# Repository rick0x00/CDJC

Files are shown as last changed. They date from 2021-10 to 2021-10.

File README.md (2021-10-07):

# Cascading 4017 Decada/Johnson Counter

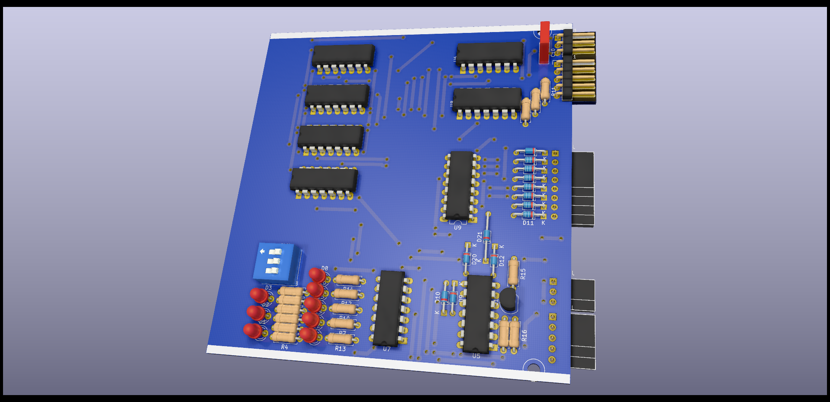
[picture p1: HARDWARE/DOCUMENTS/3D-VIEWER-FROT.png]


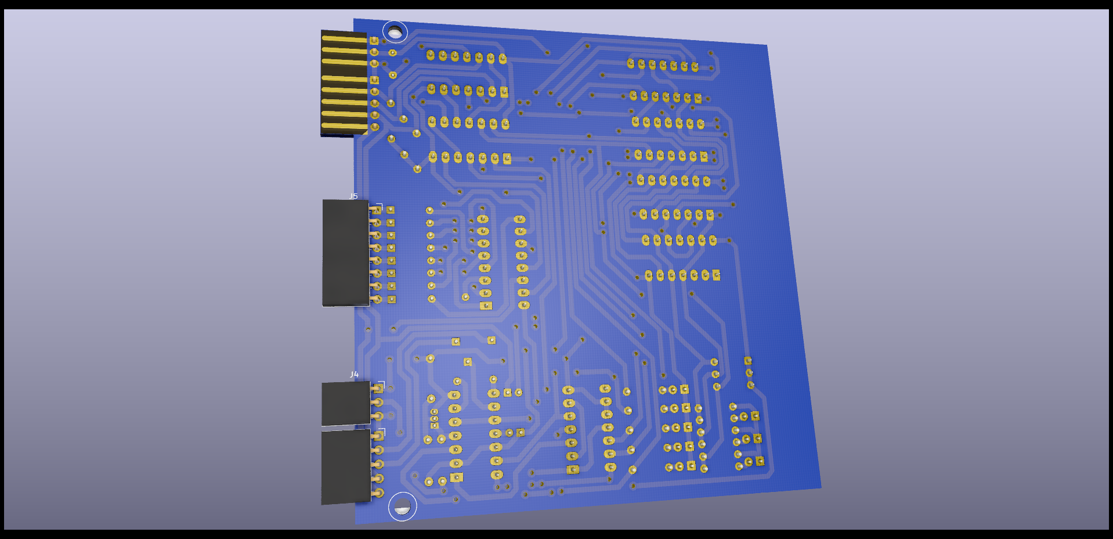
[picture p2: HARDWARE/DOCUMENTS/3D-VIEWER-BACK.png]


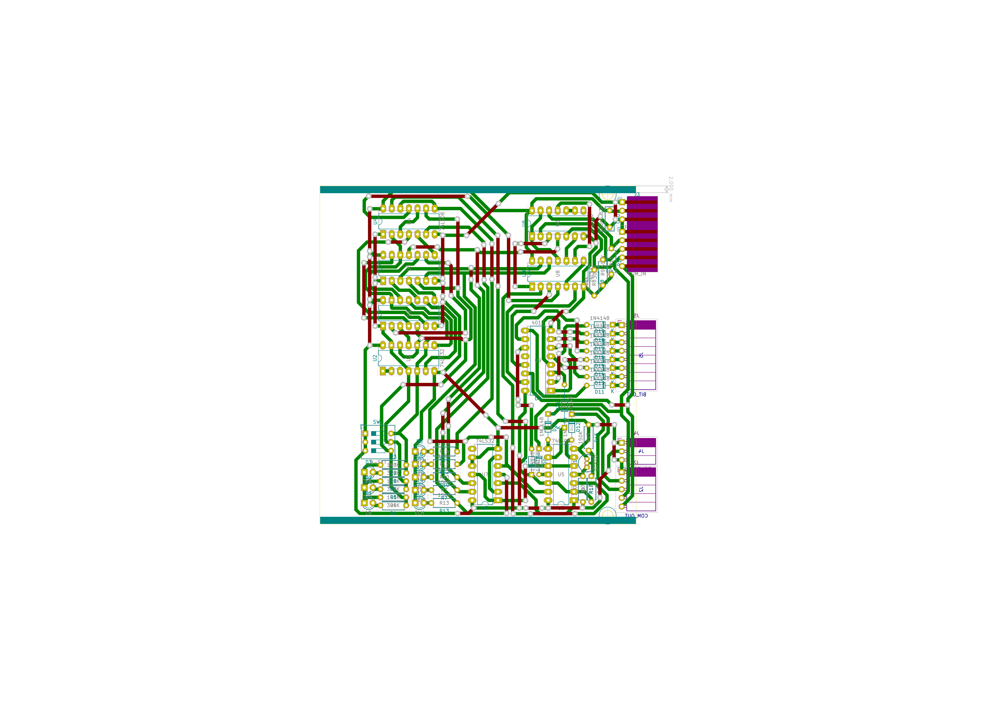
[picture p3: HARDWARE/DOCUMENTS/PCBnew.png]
PCB


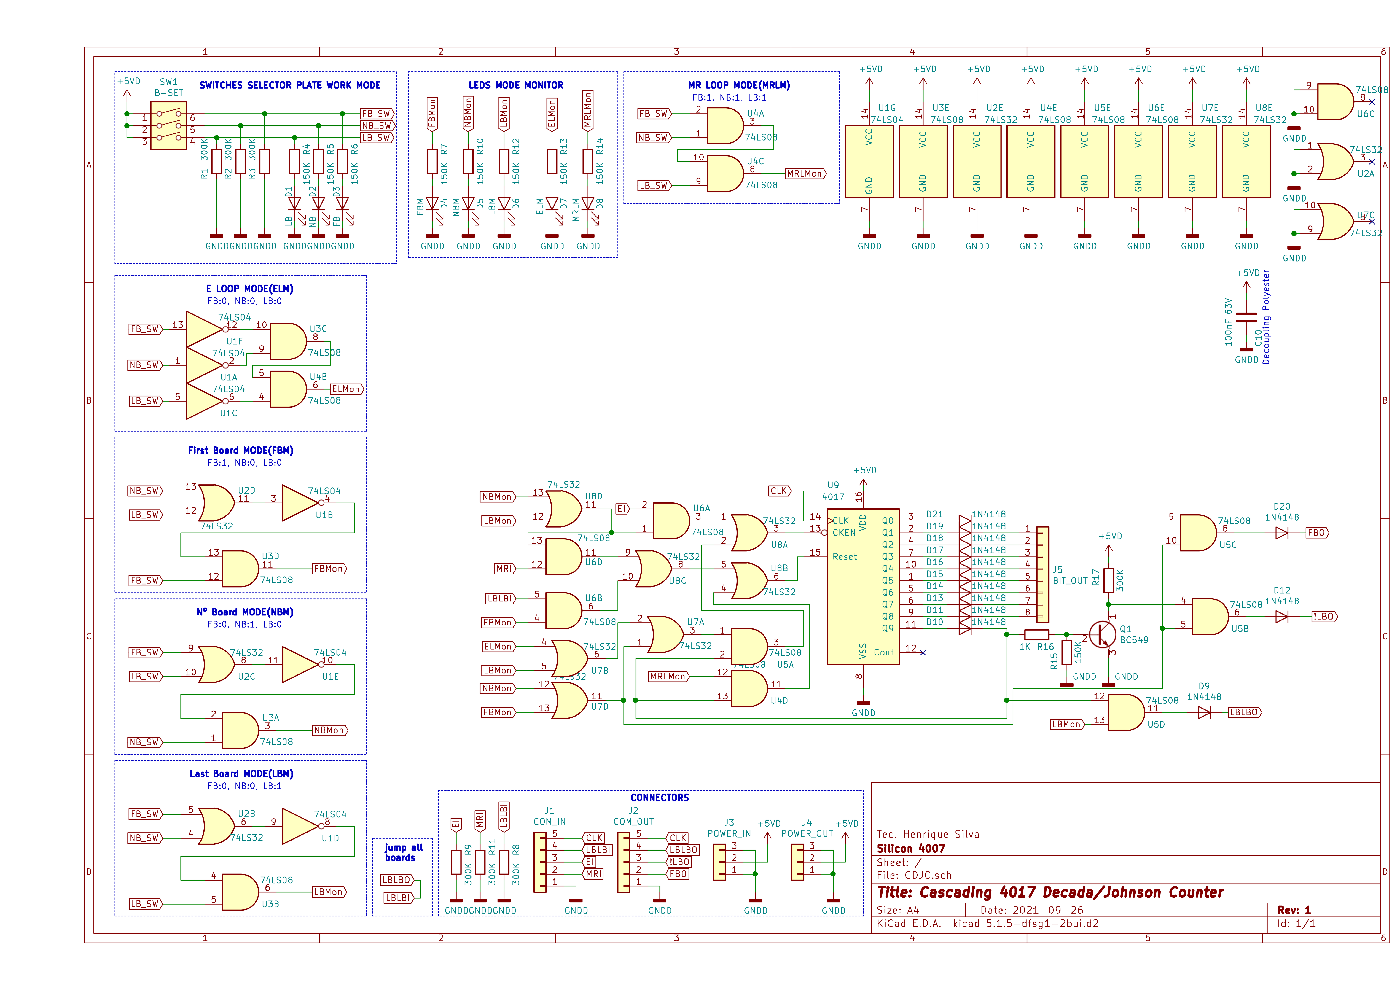
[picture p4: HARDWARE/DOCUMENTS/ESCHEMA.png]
ESCHEMA


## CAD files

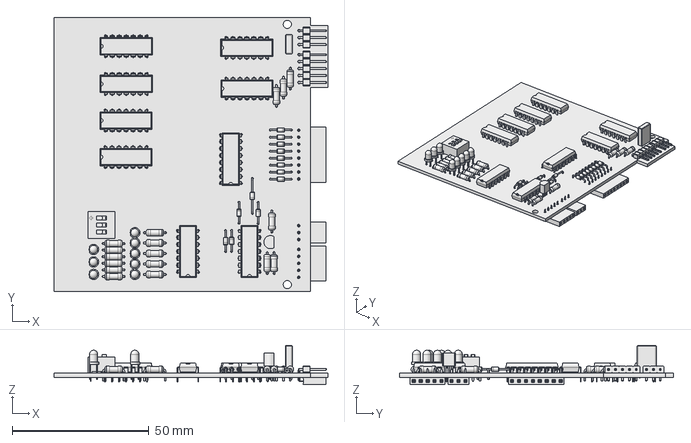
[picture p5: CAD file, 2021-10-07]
HARDWARE/CAD/FREECAD/CDJC.FCStd
100.0 x 100.0 x 14.2 mm

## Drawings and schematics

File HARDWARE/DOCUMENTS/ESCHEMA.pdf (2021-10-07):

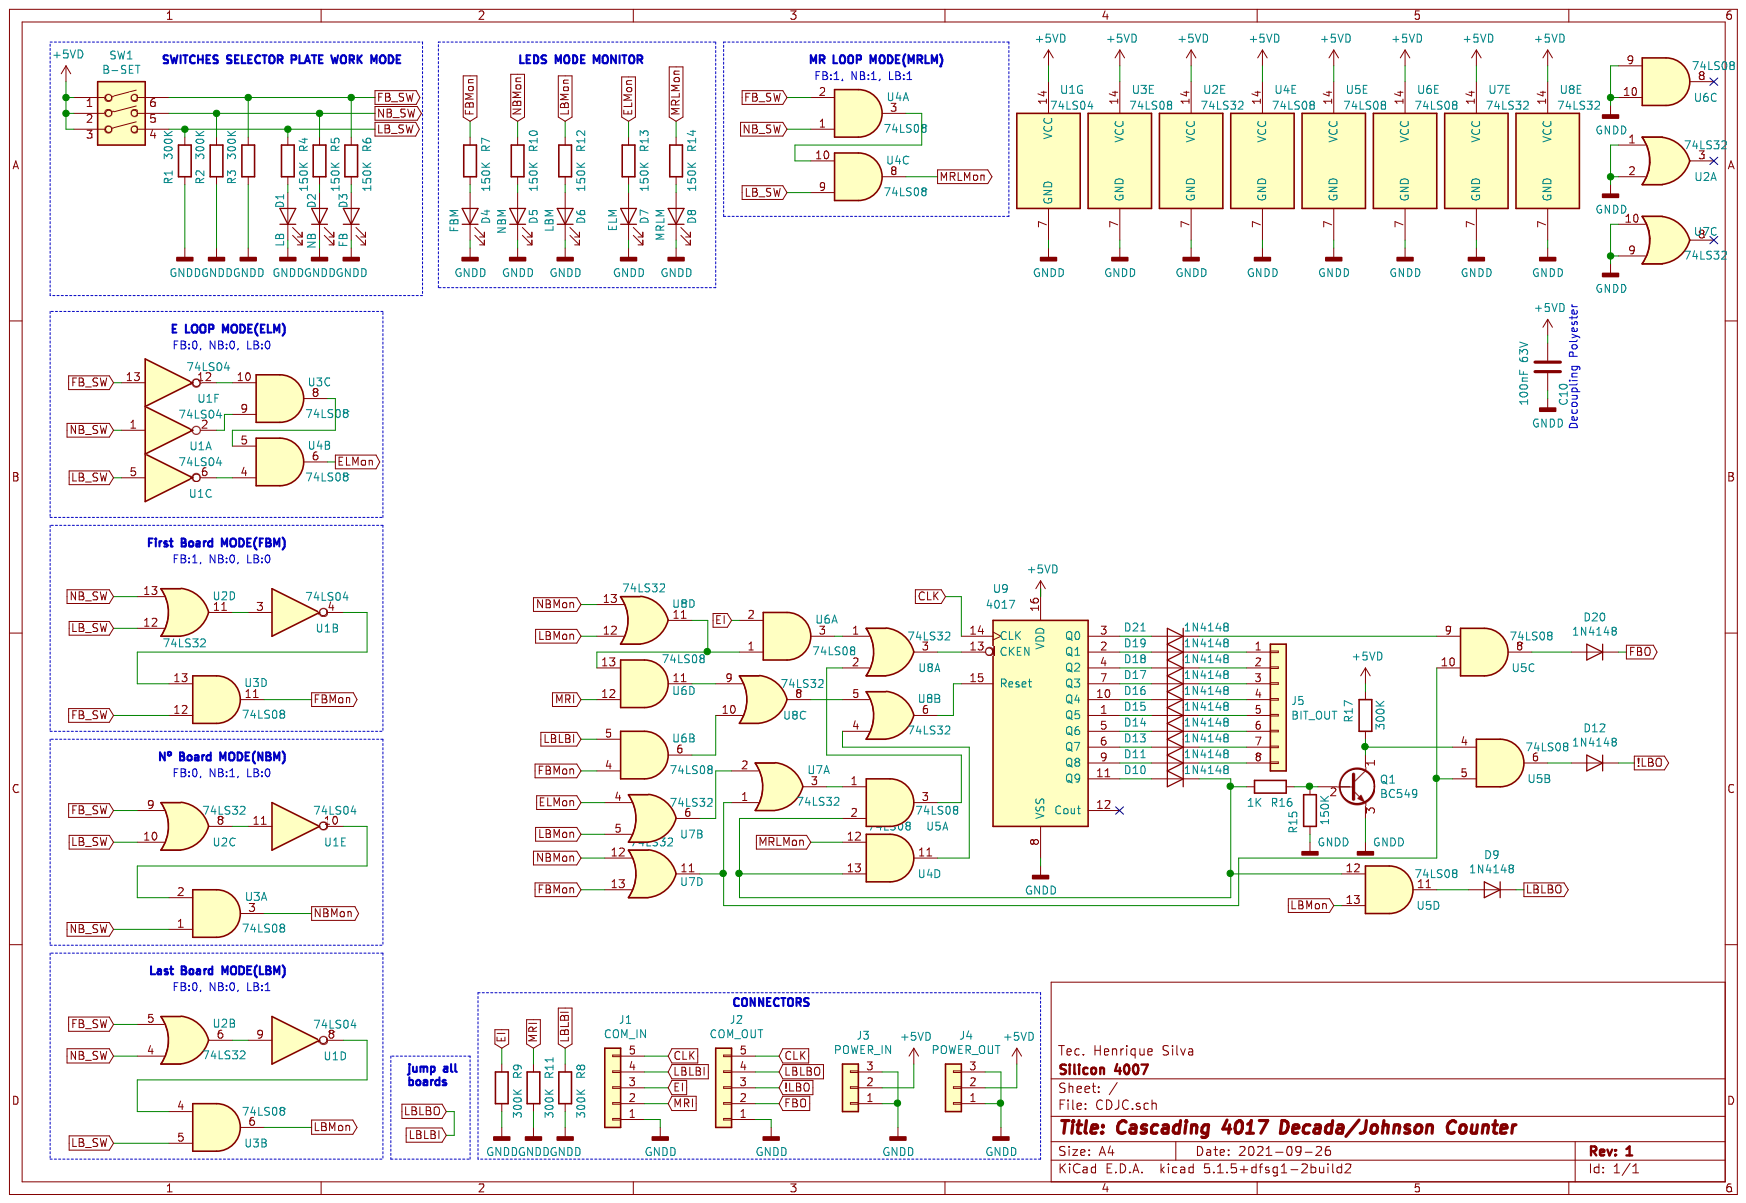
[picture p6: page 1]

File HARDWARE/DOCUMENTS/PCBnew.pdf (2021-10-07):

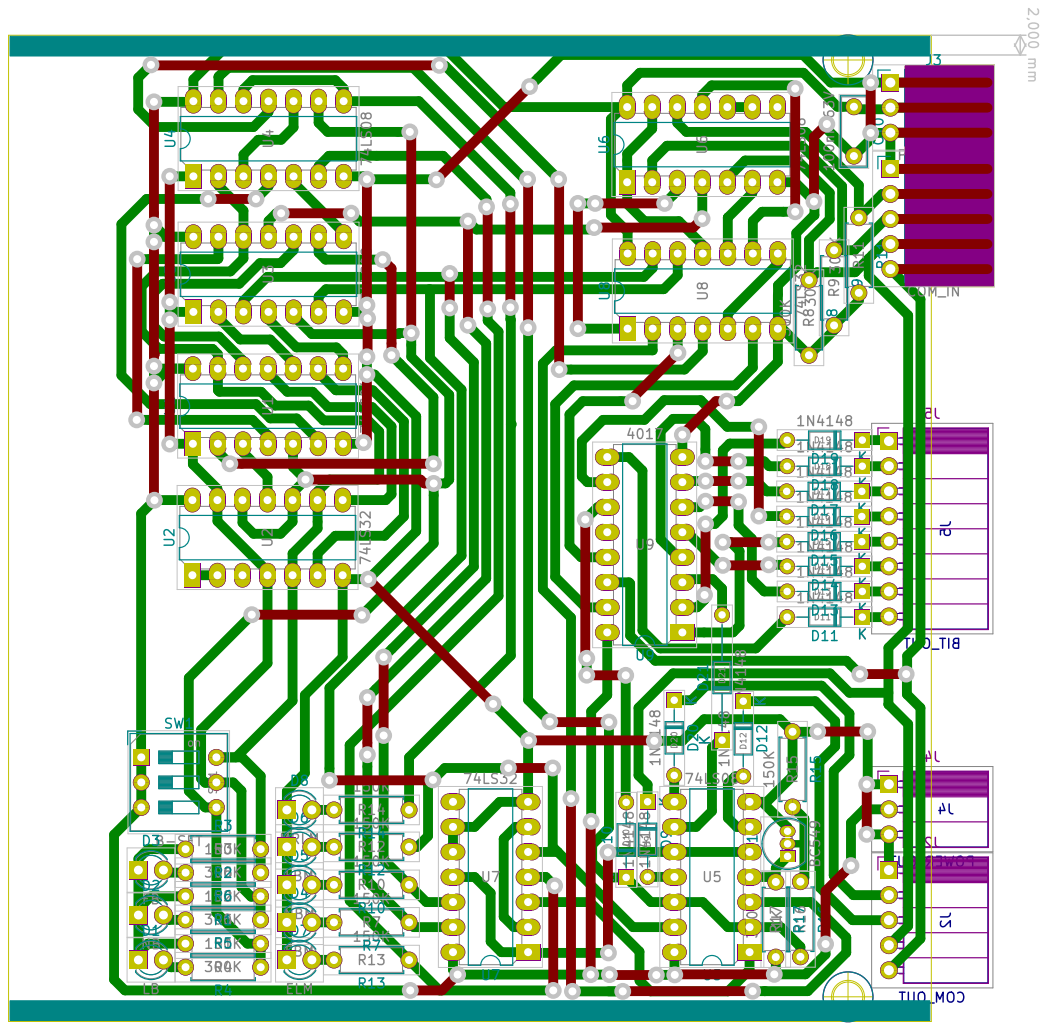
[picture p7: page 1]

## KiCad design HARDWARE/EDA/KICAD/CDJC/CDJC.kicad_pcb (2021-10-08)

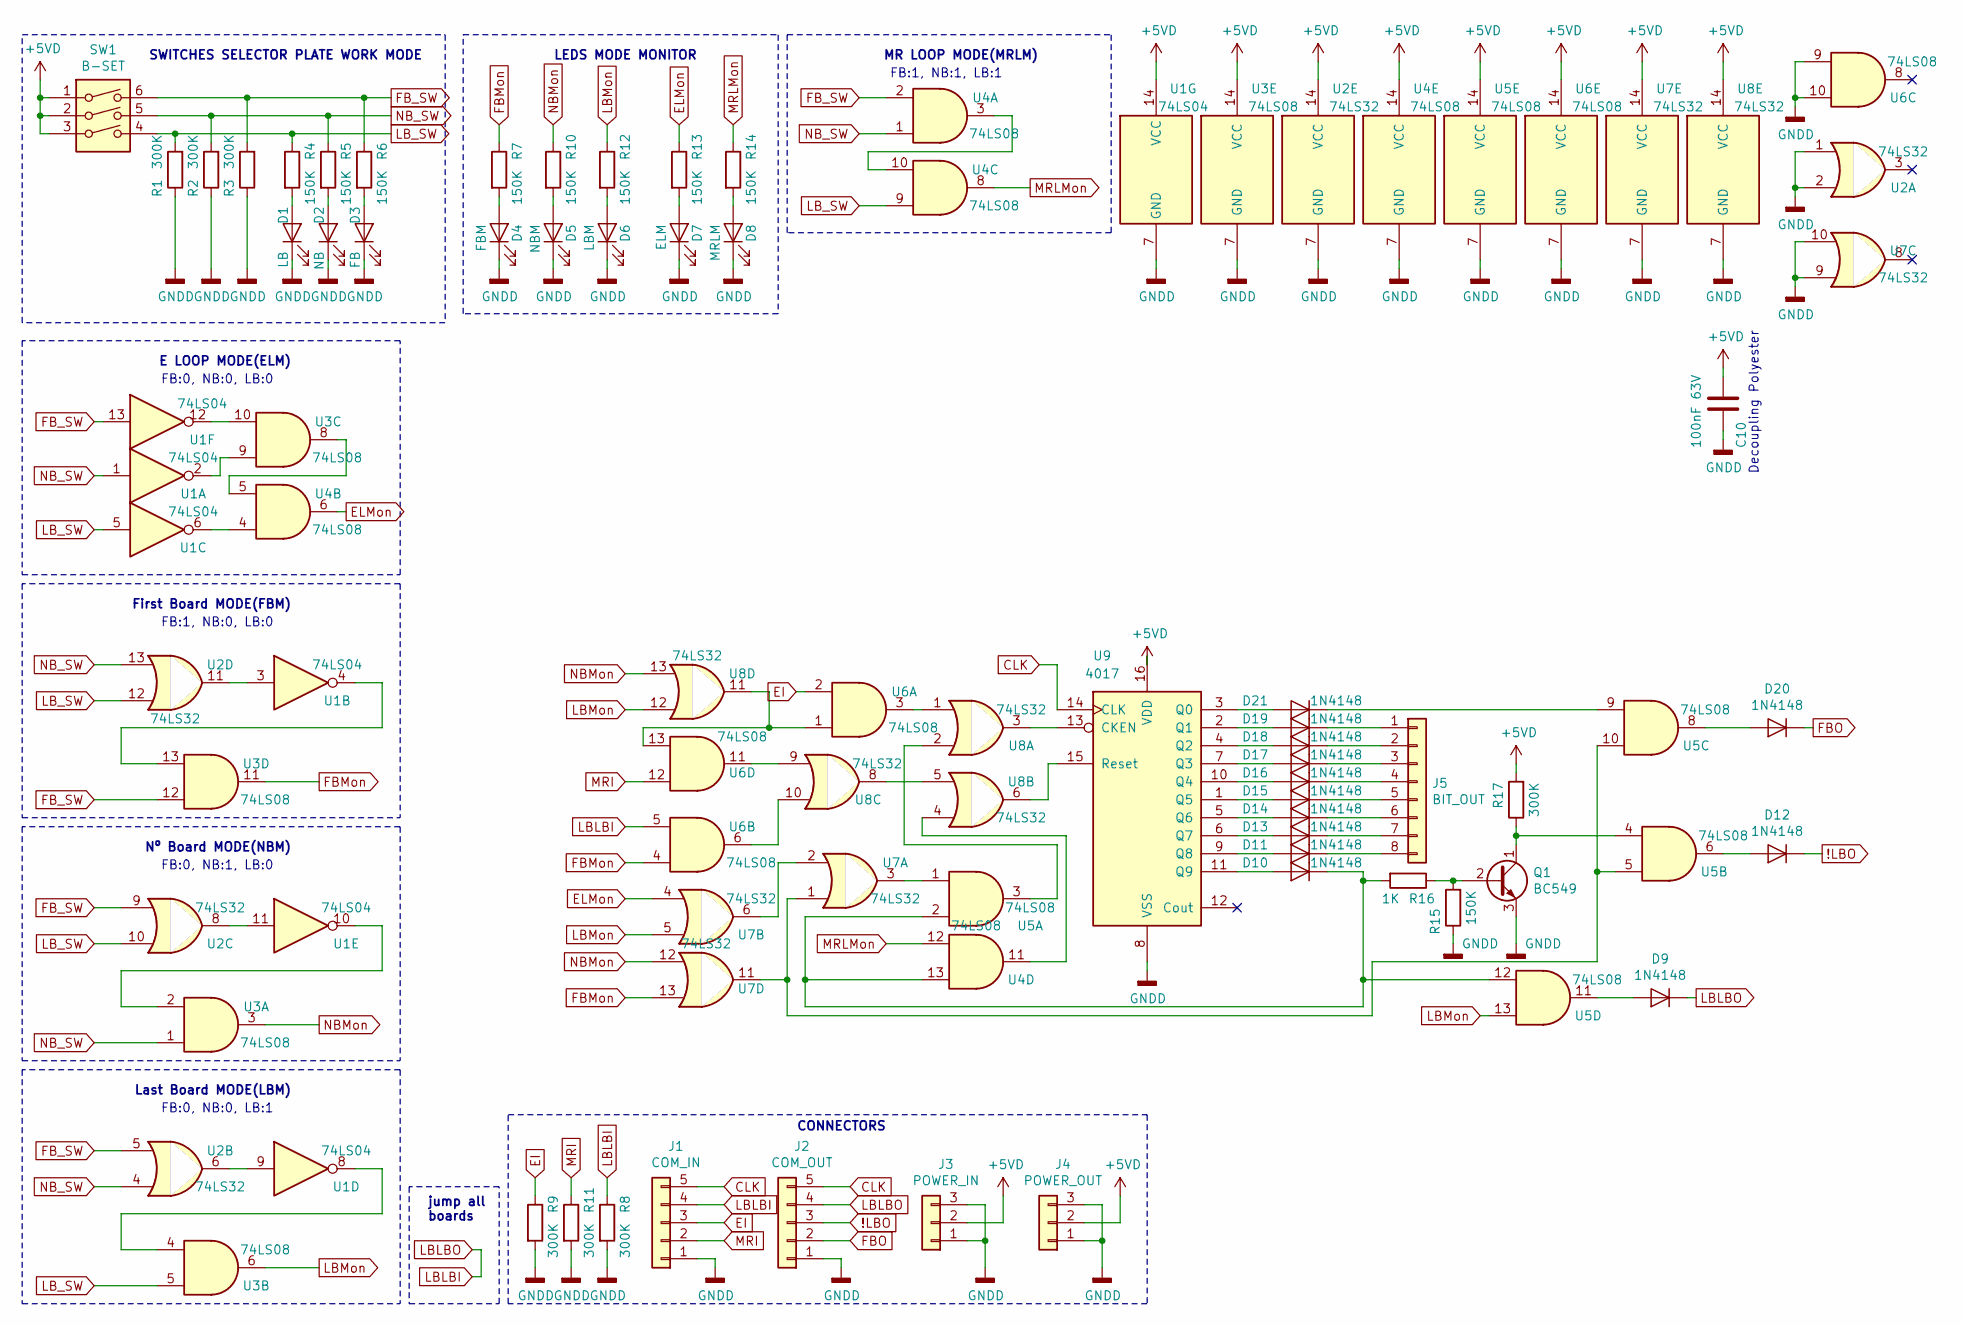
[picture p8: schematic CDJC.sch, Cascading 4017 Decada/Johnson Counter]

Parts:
C10: 100nF 63V; C_Rect_L7.0mm_W2.5mm_P5.00mm
D1: LB; LED_D3.0mm
D2: NB; LED_D3.0mm
D3: FB; LED_D3.0mm
D4: FBM; LED_D3.0mm
D5: NBM; LED_D3.0mm
D6: LBM; LED_D3.0mm
D7: ELM; LED_D3.0mm
D8: MRLM; LED_D3.0mm
D9, D10, D11, D12, D13, D14, D15, D16, D17, D18, D19, D20: 1N4148; D_DO-34_SOD68_P7.62mm_Horizontal
D21: 1N4148; D_DO-34_SOD68_P12.70mm_Horizontal
J1: COM_IN; PinHeader_1x05_P2.54mm_Horizontal
J2: COM_OUT; PinSocket_1x05_P2.54mm_Horizontal
J3: POWER_IN; PinHeader_1x03_P2.54mm_Horizontal
J4: POWER_OUT; PinSocket_1x03_P2.54mm_Horizontal
J5: BIT_OUT; PinSocket_1x08_P2.54mm_Horizontal
Q1: BC549; TO-92_Inline
R1, R2, R3, R8, R9, R11, R17: 300K; R_Axial_DIN0207_L6.3mm_D2.5mm_P7.62mm_Horizontal
R4, R5, R6, R7, R10, R12, R13, R14, R15: 150K; R_Axial_DIN0207_L6.3mm_D2.5mm_P7.62mm_Horizontal
R16: 1K; R_Axial_DIN0207_L6.3mm_D2.5mm_P7.62mm_Horizontal
SW1: B-SET; SW_DIP_SPSTx03_Slide_9.78x9.8mm_W7.62mm_P2.54mm
U1: 74LS04; DIP-14_W7.62mm_LongPads
U2, U7, U8: 74LS32; DIP-14_W7.62mm_LongPads
U3, U4, U5, U6: 74LS08; DIP-14_W7.62mm_LongPads
U9: 4017; DIP-16_W7.62mm_LongPads

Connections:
!LBO: D12.1 (K), J2.3
+5VD: C10.1, J3.2, J4.2, R17.2, SW1.1, SW1.2, SW1.3, U1.14 (VCC), U2.14 (VCC), U3.14 (VCC), U4.14 (VCC), U5.14 (VCC), U6.14 (VCC), U7.14 (VCC), U8.14 (VCC), U9.16 (VDD)
CLK: J1.5, J2.5, U9.14 (CLK)
EI: J1.3, R9.1, U6.2
ELMon: R13.1, U4.6, U7.4
FBMon: R7.1, U3.11, U6.4, U7.13
FBO: D20.1 (K), J2.2
FB_SW: R3.2, R6.1, SW1.6, U1.13, U2.5, U2.9, U3.12, U4.2
GNDD: C10.2, D1.1 (K), D2.1 (K), D3.1 (K), D4.1 (K), D5.1 (K), D6.1 (K), D7.1 (K), D8.1 (K), J1.1, J2.1, J3.1, J3.3, J4.1, J4.3, Q1.3 (E), R1.1, R2.1, R3.1, R8.2, R9.2, R11.2, R15.1, U1.7 (GND), U2.1, U2.2, U2.7 (GND), U3.7 (GND), U4.7 (GND), U5.7 (GND), U6.7 (GND), U6.9, U6.10, U7.7 (GND), U7.9, U7.10, U8.7 (GND), U9.8 (VSS)
LBLBI: D9.1 (K), J1.4, J2.4, R8.1, U6.5
LBMon: R12.1, U3.6, U5.13, U7.5, U8.12
LB_SW: R1.2, R4.1, SW1.4, U1.5, U2.10, U2.12, U3.5, U4.9
MRI: J1.2, R11.1, U6.12
MRLMon: R14.1, U4.8, U4.12
NBMon: R10.1, U3.3, U7.12, U8.13
NB_SW: R2.2, R5.1, SW1.5, U1.1, U2.4, U2.13, U3.1, U4.1
unnamed: D1.2 (A), R4.2
unnamed: D2.2 (A), R5.2
unnamed: D3.2 (A), R6.2
unnamed: D4.2 (A), R7.2
unnamed: D5.2 (A), R10.2
unnamed: D6.2 (A), R12.2
unnamed: D7.2 (A), R13.2
unnamed: D8.2 (A), R14.2
unnamed: D9.2 (A), U5.11
unnamed: D10.1 (K), R16.2, U4.13, U5.2, U5.12
unnamed: D10.2 (A), U9.11 (Q9)
unnamed: D11.1 (K), J5.8
unnamed: D11.2 (A), U9.9 (Q8)
unnamed: D12.2 (A), U5.6
unnamed: D13.1 (K), J5.7
unnamed: D13.2 (A), U9.6 (Q7)
unnamed: D14.1 (K), J5.6
unnamed: D14.2 (A), U9.5 (Q6)
unnamed: D15.1 (K), J5.5
unnamed: D15.2 (A), U9.1 (Q5)
unnamed: D16.1 (K), J5.4
unnamed: D16.2 (A), U9.10 (Q4)
unnamed: D17.1 (K), J5.3
unnamed: D17.2 (A), U9.7 (Q3)
unnamed: D18.1 (K), J5.2
unnamed: D18.2 (A), U9.4 (Q2)
unnamed: D19.1 (K), J5.1
unnamed: D19.2 (A), U9.2 (Q1)
unnamed: D20.2 (A), U5.8
unnamed: D21.1 (K), U5.9
unnamed: D21.2 (A), U9.3 (Q0)
unnamed: Q1.1 (C), R17.1, U5.4
unnamed: Q1.2 (B), R15.2, R16.1
unnamed: U1.2, U3.9
unnamed: U1.3, U2.11
unnamed: U1.4, U3.13
unnamed: U1.6, U4.4
unnamed: U1.8, U3.4
unnamed: U1.9, U2.6
unnamed: U1.10, U3.2
unnamed: U1.11, U2.8
unnamed: U1.12, U3.10
unnamed: U3.8, U4.5
unnamed: U4.3, U4.10
unnamed: U4.11, U8.4
unnamed: U5.1, U7.3
unnamed: U5.3, U8.2
unnamed: U5.5, U5.10, U7.1, U7.11
unnamed: U6.1, U6.13, U8.11
unnamed: U6.3, U8.1
unnamed: U6.6, U8.10
unnamed: U6.11, U8.9
unnamed: U7.2, U7.6
unnamed: U8.3, U9.13 (CKEN)
unnamed: U8.5, U8.8
unnamed: U8.6, U9.15 (Reset)

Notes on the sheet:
SWITCHES SELECTOR PLATE WORK MODE
MR LOOP MODE(MRLM)
FB:1, NB:1, LB:1
E LOOP MODE(ELM)
FB:0, NB:0, LB:0
First Board MODE(FBM)
FB:1, NB:0, LB:0
Nº Board MODE(NBM)
FB:0, NB:1, LB:0
Last Board MODE(LBM)
FB:0, NB:0, LB:1
LEDS MODE MONITOR
Decoupling Polyester
CONNECTORS
jump all boards

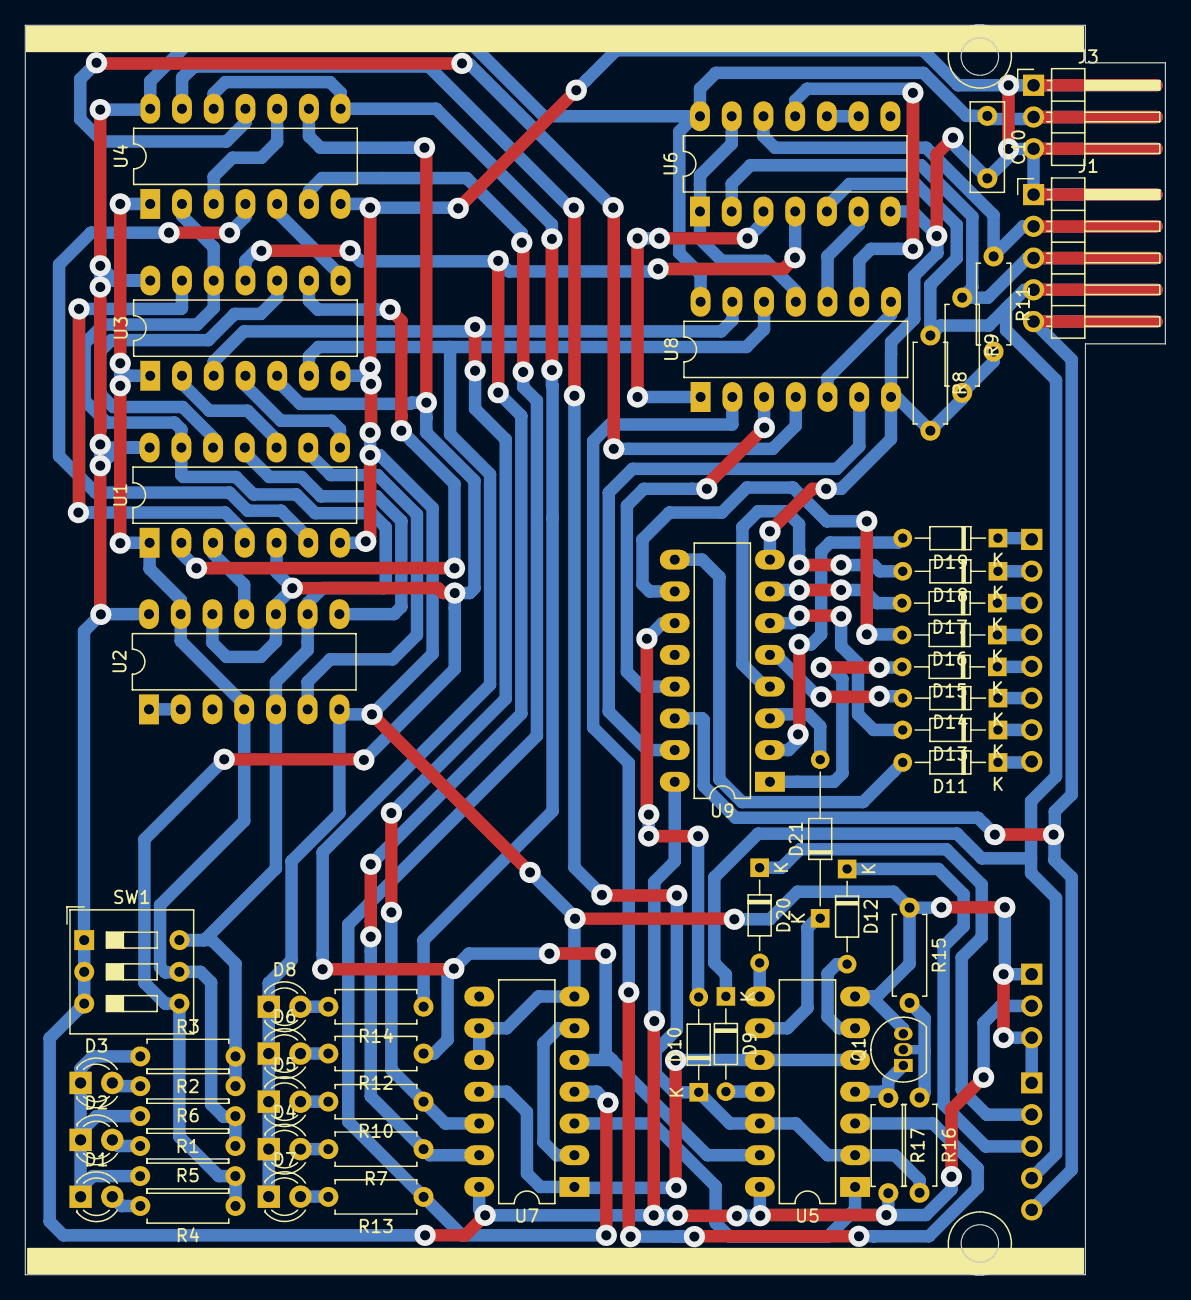
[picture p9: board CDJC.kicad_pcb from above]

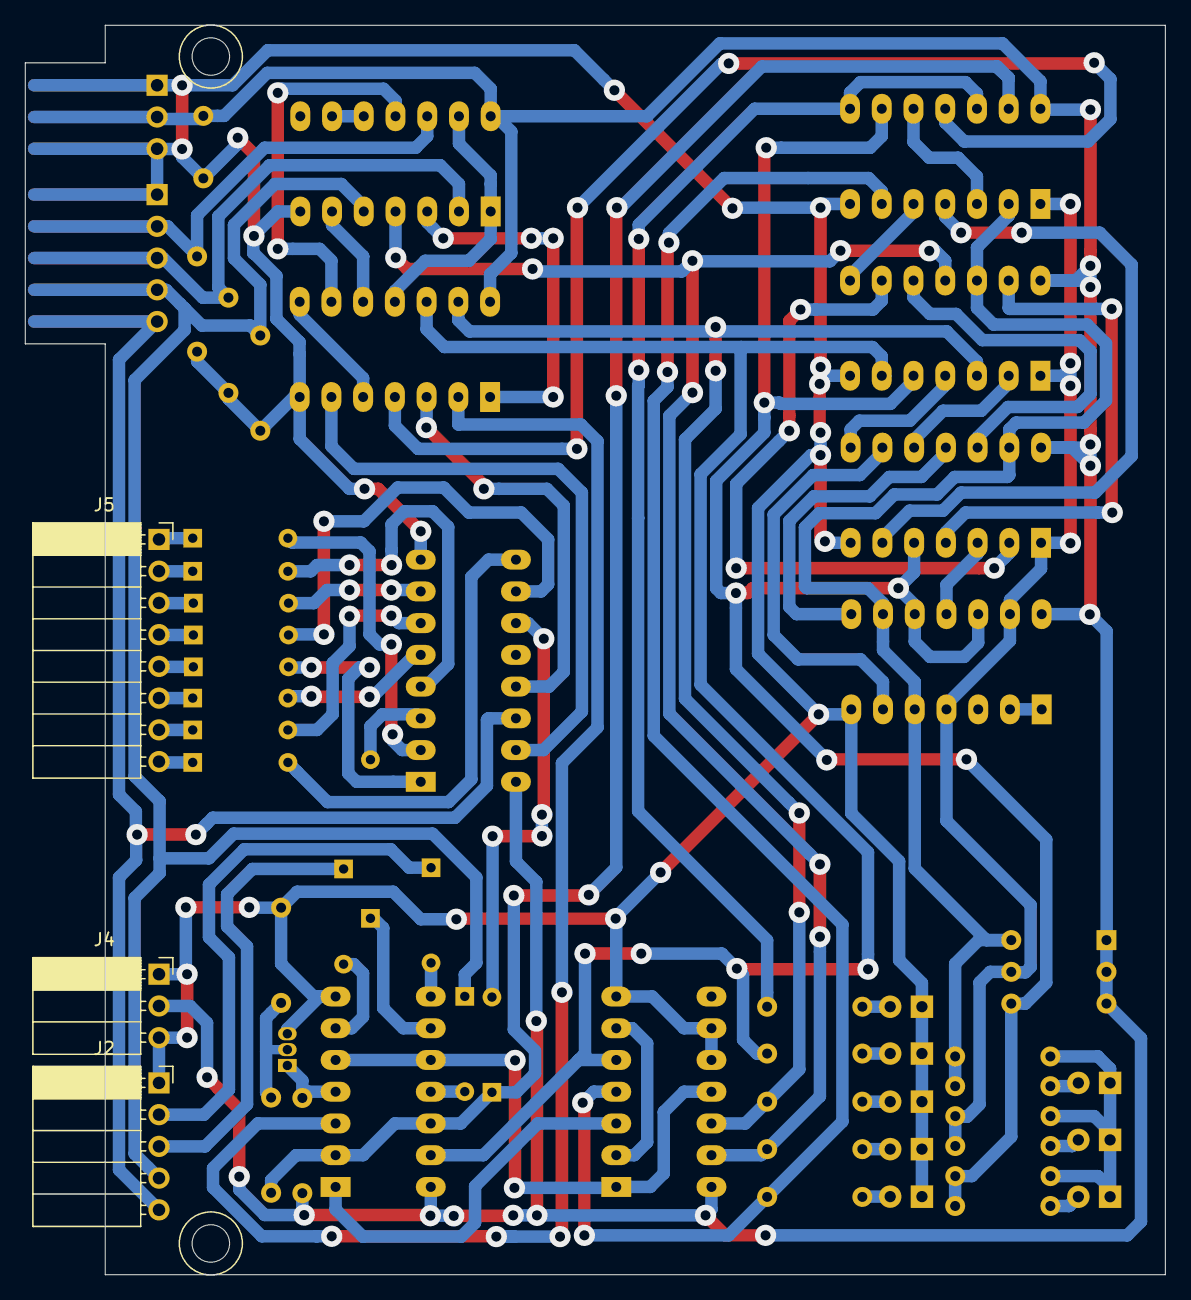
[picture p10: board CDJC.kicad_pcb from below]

Board: 2 copper layers, 91.2 x 100.0 mm, 55 parts (3 on the bottom side), 72 nets.

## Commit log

2021-09-26 add kicad project
    [CDJC.kicad_pcb, CDJC.sch]
2021-09-26 kicad project start
2021-09-26 CONTROL SWITCHS OK
    [CDJC.sch]
2021-09-26 CONNECTORS OK
    [CDJC.sch]
2021-09-26 capacitor decoupling OK
    [CDJC.sch]
2021-09-26 OUTPUTS 4017 PK
    [CDJC.sch]
2021-09-26 CONNECTORS REMIX
    [CDJC.sch]
2021-09-26 finished project
    [CDJC.sch]
2021-09-27 paused PCB design
    [CDJC.sch]
2021-09-27 i am crazy
    [CDJC.kicad_pcb, CDJC.sch]
2021-09-27 PCI connector OK
    [CDJC.kicad_pcb]
2021-09-27 stop work
    [CDJC.kicad_pcb]
2021-09-28 work stop
    [CDJC.kicad_pcb]
2021-09-28 adjust layout pcb
    [CDJC.kicad_pcb, CDJC.sch]
2021-09-29 Adjust resitor alingment
    [CDJC.kicad_pcb]
2021-09-29 ajust dip and leds mode set
    adjust jumper to set mode
    [CDJC.kicad_pcb, CDJC.sch]
2021-09-29 adjust footprint to bc 547
    [CDJC.kicad_pcb, CDJC.sch]
2021-09-29 stop work, go home
    [CDJC.kicad_pcb, CDJC.sch]
2021-09-30 pause work for sleep
    [CDJC.kicad_pcb, CDJC.sch]
2021-09-30 adjusting PCB
    [CDJC.kicad_pcb]
2021-10-02 pause work
    [CDJC.kicad_pcb, CDJC.sch]
2021-10-03 pause work0
    [CDJC.kicad_pcb, CDJC.sch]
2021-10-04 ajdust PCB
    [CDJC.kicad_pcb]
2021-10-05 remaining editions
    [CDJC.kicad_pcb]
2021-10-05 adjusts in PCB
    [CDJC.kicad_pcb, CDJC.sch]
2021-10-05 Re-associate footprints by reference
    [CDJC.kicad_pcb, CDJC.sch]
2021-10-07 U7 pre adjust in PCB
    [CDJC.kicad_pcb]
2021-10-07 finished V1 board
    [CDJC.kicad_pcb]
2021-10-07 tentativa de conversão 3D
    [CDJC.FCStd, CDJC.dsn]
2021-10-08 PCB finished
    [CDJC.dsn, CDJC.kicad_pcb, CDJC_Autorouting-test.dsn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]
